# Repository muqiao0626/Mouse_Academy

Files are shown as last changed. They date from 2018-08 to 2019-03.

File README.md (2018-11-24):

# Mouse Academy

## Overview

Mouse Academy is an integrated platform for automated mice training. It is made of a social home cage, a radio frequency identification (RFID) access control tunnel and a training box. Mice are grouped together in the home cage where they can get free access to food and shelter. Water is provided only in the training box. Each mouse is implanted with a specific RFID chip whose information can be read from the RFID sensors. Based on the information from the RFID sensors, an Arduino circuit controls the opening of the gates, allowing only one animal at a time to access the training box. Once a mouse enters the training box, a protocol is initiated to train the mouse on a specific task using water rewards, and a video recording of the mouse’s behaviors is performed. The training box is controlled by Bpod, an open-source behavior control system (https://github.com/sanworks/Bpod).

## Content

## 1. Design files

The folder contains several CAD files for the hardware

## 2. Firmware and software

The folders MATLAB_PC and Python_RasPi contain the firmware and software designed for the specific system. In both folders, you can find:

### Firmware: Arduino program for RFID access control

#### Documentation

The code was written in Arduino language which has been tested on ARDUINO (IDE) 1.8.5. To run the code, you need to install the following packages:
```
Servo.h
```

#### Instruction in compiling and uploading the code

Compile the code in ARDUINO (IDE) 1.8.5 and upload it to Arduino Mega 2560

### Software and the instruction in running the software

Check the software folder and the corresponding txt files for instructions

## 3. Licence

These files are freely available under the terms of General Public License v3.0 (enclosed with this repository)

## 4. Acknowledgement

We thank Josh Sanders (Sanworks) for his advice on how to incorporate Bpod in Mouse Academy.

## 5. Contact

For more questions, please contact Mu Qiao at muqiao@caltech.edu and Sarah Sam at ssam@caltech.edu

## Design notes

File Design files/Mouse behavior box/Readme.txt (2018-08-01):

Note: This design for the mouse behavior box is undergoing validation.
It will almost certainly be revised many times in the coming year. A bill of materials is available on the Bpod wiki. JS, June 2015

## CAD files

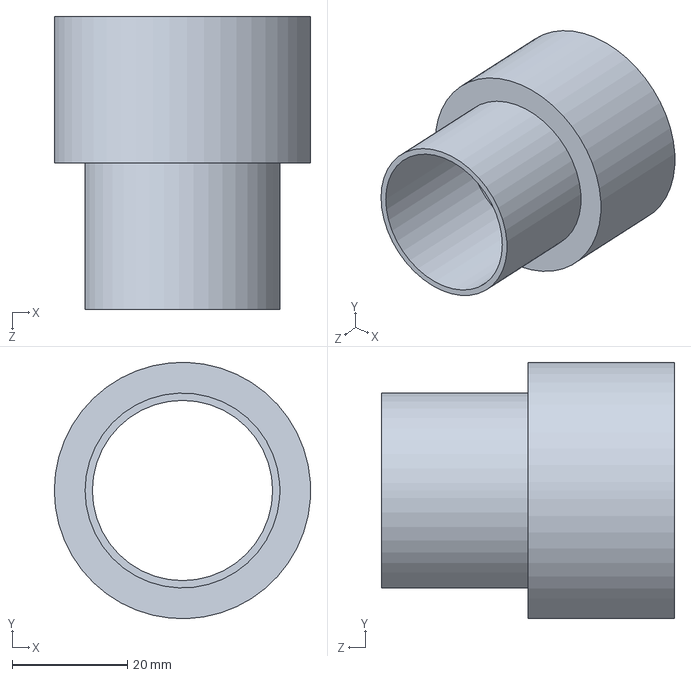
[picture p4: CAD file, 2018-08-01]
Design files/Adapter/adapter.SLDPRT
44.5 x 44.4 x 50.8 mm

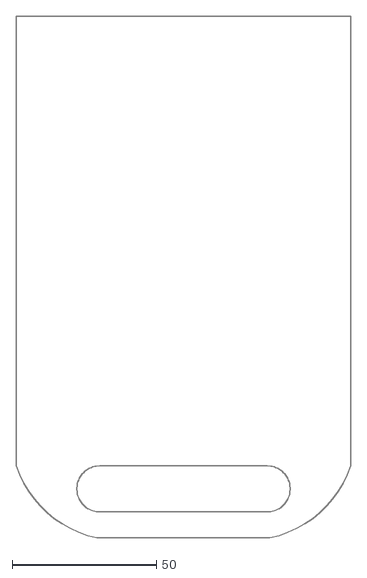
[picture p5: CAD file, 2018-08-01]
Design files/Mouse behavior box/2D DXF Laser Cut/Laser_Clear_3mm.dxf
116.0 x 181.0

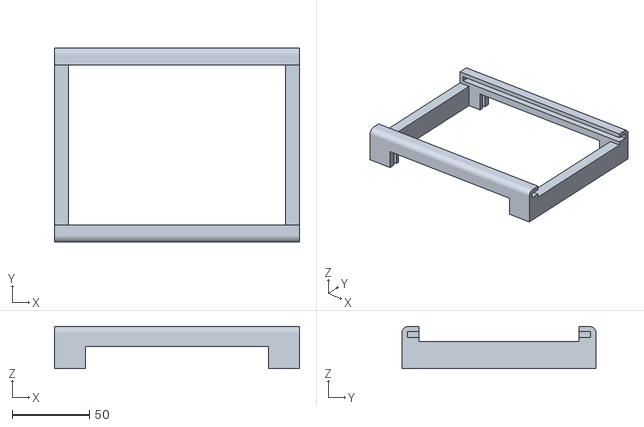
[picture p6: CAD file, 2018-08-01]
Design files/Mouse behavior box/3D STL Print/MouseBox_3dPrint_Top.stl
159.0 x 126.1 x 27.5

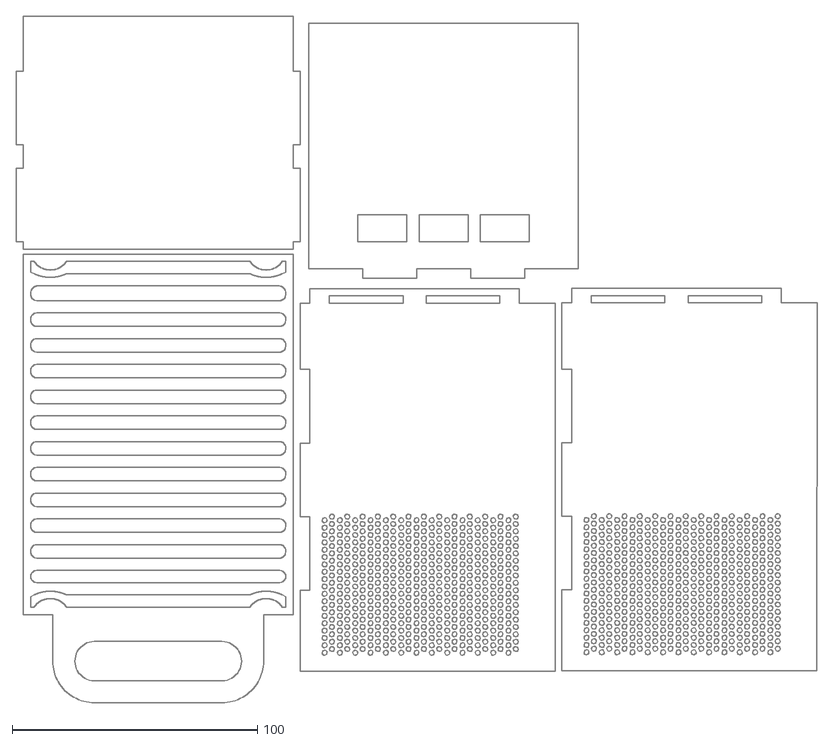
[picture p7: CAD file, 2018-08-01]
Design files/Mouse behavior box/2D DXF Laser Cut/Laser_White_3mm.dxf
326.7 x 280.0

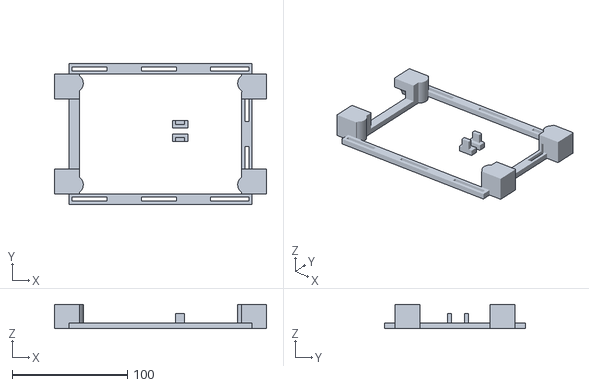
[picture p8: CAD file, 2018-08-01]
Design files/Mouse behavior box/3D STL Print/MouseBox_3dPrint_Base.stl
184.0 x 122.0 x 21.0

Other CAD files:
Design files/Adapter/adapter.STL

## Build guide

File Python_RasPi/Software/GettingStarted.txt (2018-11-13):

1) Activate python 3.5 environment with the command ~$ source activate py35
2) From the 'Software' directory, run ~$ python appendPath.py to add Mouse_Academy subfolders to the python search path.
3) Run ~$ python SoftwareTests.py to verify setup.
4) From the 'Modules' directory, run Enrollment.py to scan RFID tags and save tag IDs to file.
5) Valves dispense precise amounts of fluid by opening for a specific amount of time. From Software directory, run:
~$ python Calibrate/Calibrate.py <valve number> <pulse duration> <number of pulses>
For instance, to add a calibration point of 30 ms for valve 1 with 200 pulses, run command:
~$ python Calibrate/Calibrate.py 1 30 200
then enter the amount of water dispensed when prompted. Use at least 3 calibration points. Calibration curves are saved in the 'Calibrate' folder.

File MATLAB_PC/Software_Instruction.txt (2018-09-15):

# Software instruction
# Mu Qiao July/2018

The code was written in Matlab and has been tested under Matlab R2016a. To run the code, copy all the files under /Software/Matlab_PC/ into the MATLAB folder. Modify the ProtocolFiles.xlsx to include all the training procedures. The format of the excel file is: Procedure_name, Threshold_for_downgrade, Threshold_for_upgrade, Trials_in_a_session.

First, run Initialization.m to initialize the program. Then, run Master.m. The program runs in an infinite loop. To exit running, pause the program and then stop the Master.m program.

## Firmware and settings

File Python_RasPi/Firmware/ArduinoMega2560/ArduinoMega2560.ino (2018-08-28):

#include <Servo.h>
#include <stdio.h>

const int servoPin1 = 8;
const int servoPin2 = 9;

const int FSR_PIN1 = A0; // Pin connected to FSR/resistor divider
const int FSR_PIN2 = A1; // Pin connected to FSR/resistor divider
const float VCC = 5; // Measured voltage of Ardunio 5V line
const float R_DIV = 3300.0; // Measured resistance of 3.3k resistor

const int highWrite = 170;
const int lowWrite = 5;

const char readCompleteMsg[18] = "read tag complete";
const char openMsg[19] = "open door complete";
const char closeMsg[20] = "close door complete";
const char obstructMsg[24] = "obstruction encountered";
int idLen = 12;

char currentTag[13] = "000000000000";

Servo servo1;
Servo servo2;

int RFIDResetPin1 = 11;
int RFIDResetPin2 = 12;
int RFIDResetPin3 = 13;

char tag1[13];
char tag2[13];
char tag3[13];
float fsrForce;

const char blankTag[13] = "000000000000";
void setTag1(char newTag[13]) {
  for (int i = 0; i < 13; i++) {
    tag1[i] = newTag[i];
  }
}
void setTag2(char newTag[13]) {
  for (int i = 0; i < 13; i++) {
    tag2[i] = newTag[i];
  }
}
void setTag3(char newTag[13]) {
  for (int i = 0; i < 13; i++) {
    tag3[i] = newTag[i];
  }
}

void setup() {
  Serial.begin(9600);
  Serial.println("Mega is setting up...");
  Serial1.begin(9600);
  Serial2.begin(9600);
  Serial3.begin(9600);
  setTag1(blankTag);
  setTag2(blankTag);
  setTag3(blankTag);
  //reset RFID readers
  pinMode(RFIDResetPin1, INPUT);
  //digitalWrite(RFIDResetPin1, HIGH);
  pinMode(RFIDResetPin2, INPUT);
  //digitalWrite(RFIDResetPin2, HIGH);
  pinMode(RFIDResetPin3, INPUT);
  //digitalWrite(RFIDResetPin3, HIGH);

  pinMode(FSR_PIN1, INPUT);
  pinMode(FSR_PIN2, INPUT);

  servo1.attach(servoPin1, 400, 1900);
  delay(50);
  //openDoor(servo1, 1);
  //delay(50);
  servo2.attach(servoPin2, 500, 2000);
  delay(50);
  //closeDoor(servo2, 2);
  //delay(50);
  Serial.println("Mega is ready.");

}

void loop() {
  readTag(1);
  readTag(2);
  readTag(3);

  if (Serial.available() >= 2) {
    char commandRead = Serial.read();
    char idRead = Serial.read();

    //CHECKING FOR READ COMMAND
    if (commandRead == '8') {

      Serial.println(readCompleteMsg);
      if (idRead == '1') {
        Serial.println(tag1);
        setTag1(blankTag);
      }
      else if (idRead == '2') {
        Serial.println(tag2);
        setTag2(blankTag);
      }
      else if (idRead == '3') {
        Serial.println(tag3);
        setTag3(blankTag);
      }

    }

    //CHECKING FOR OPEN DOOR COMMAND
    else if (commandRead == '6') {
      if (idRead == '1') {
        openDoor(servo1);
      }
      if (idRead == '2') {
        openDoor(servo2);
      }
      Serial.println(openMsg);
    }

    //CHECKING FOR CLOSE DOOR COMMAND
    else if (commandRead == '7') {
      int closed = 0;
      if (idRead == '1') {
        closed = closeDoor(servo1, 1);
        if (closed == 1) {
          Serial.println(closeMsg);
        }
      }
      if (idRead == '2') {
        closed = closeDoor(servo2, 2);
        if (closed == 1) {
          Serial.println(closeMsg);
        }
      }
    }

  }
  delay(10);
}







// READ A TAG FROM A SINGLE RFID READER
void readTag(int tagNum) {
  currentTag[13] = "000000000000";
  HardwareSerial* serPointer;
   int address;

  if (tagNum == 1){
    serPointer = &Serial1;
  }
  else if (tagNum == 2){
    serPointer = &Serial2;
  }
  else if (tagNum == 3){
    serPointer = &Serial3;
  }
  boolean reading = false;
  int i = 0;
  int readByte;
  char peekByte;
  if (serPointer->available() >= 10) {
    peekByte = serPointer->peek(); //peep next available byte
    if (peekByte == 2) {
      readByte = serPointer->read();
      reading = true; //begining of tag

      while (reading == true) {
        readByte = serPointer->read();
        if (readByte == 3) {

          if (tagNum == 1) {
            setTag1(currentTag);
          }
          else if (tagNum == 2) {
            setTag2(currentTag);
          }
          else if (tagNum == 3) {
            setTag3(currentTag);
          }
          reading = false; //end of tag
        }

        else if (readByte != 10 && readByte != 13) {
          //store the tag
          if (i < sizeof(currentTag)) {
            currentTag[i] = readByte;
          }
          i++;
        }
        delay(2);
      }
    }
    else {
      reading = false;
    }
  }
}

int closeDoor(Servo servo, int servonum) {
  int pos = servo.read();
  int closed = 0;
  currentForce(servonum);
  float forceInit = fsrForce;
  float forceNow;
  //don't bother checking force at beginning and end
  for (int theta = pos; theta < highWrite - 6; theta += 6) {

    if (theta < lowWrite + 6 || theta > highWrite - 6) {
      servo.write(theta);
      delay(5);
      closed = 1;
    }



    else {
      servo.write(theta);
      delay(5);
      currentForce(servonum);
      forceNow = fsrForce - forceInit;
      if (forceNow > 10.0) {
        //reopen door
        servo.write(lowWrite);
        //print serial message that close door failed
        Serial.println(obstructMsg);
        //Serial.print(forceInit);
       // Serial.print(" forceNow: ");
        //Serial.println(forceNow);
        return 0;
      }
    }
  }
  //Serial.print("initForce ");
  //Serial.println(forceInit);
  return 1;
}

void openDoor(Servo servo) {
  int pos = servo.read();
  for (int theta = pos; theta > lowWrite + 3; theta -= 3) {
    servo.write(theta);
    delay(15);
  }
}


void currentForce(int doornum)
{
  int fsrADC;
  if (doornum == 1) {
    fsrADC = analogRead(FSR_PIN1);
  }
  else if (doornum == 2) {

    fsrADC = analogRead(FSR_PIN2);
  }
  // If the FSR has no pressure, the resistance will be
  // near infinite. So the voltage should be near 0.
  if (fsrADC != 0) // If the analog reading is non-zero
  {
    // Use ADC reading to calculate voltage:
    float fsrV = fsrADC * VCC / 1023.0;
    // Use voltage and static resistor value to
    // calculate FSR resistance:
    float fsrR = R_DIV * (VCC / fsrV - 1.0);
    float fsrG = 1.0 / fsrR;
    // Serial.println("Resistance: " + String(fsrR) + " ohms");
    // Guesstimate force based on slopes in figure 3 of
    // FSR datasheet:
    // Break parabolic curve down into two linear slopes:
    if (fsrR <= 600)
      fsrForce = (fsrG - 0.00075) / 0.00000032639;
    else
      fsrForce =  fsrG / 0.000000642857;

  }
  else{
    fsrForce = 0;
  }
}

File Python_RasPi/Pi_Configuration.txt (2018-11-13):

Raspberry pi configuration
Sarah Sam 08/20/18

1. Installing the OS
a) Purchase an Adafruit SD card that has NOOBS already installed OR
b) Download NOOBS from https://www.raspberrypi.org/downloads/noobs/ 
SD card should be 4-32 GB
extract downloaded file, copy all files from noobs directory to SD card root directory
2. Configure raspberry pi
a) change password
b) time preferences
c) language & keyboard
3. Python distribution: miniconda3
a) install per: https://stackoverflow.com/questions/39371772/how-to-install-anaconda-on-raspberry-pi-3-model-b 
1. wget http://repo.continuum.io/miniconda/Miniconda3-latest-Linux-armv7l.sh
2. md5sum Miniconda3-latest-Linux-armv7l.sh
3. bash Miniconda3-latest-Linux-armv7l.sh
4. Install numpy and pyserial
a) find python version
1. conda update conda
2. conda install anaconda-client
3. conda search "^python$"
b) create virtual python environment (ex. for python version 3.4.3)
1. conda create –n py34 python=3.4.3
2. source activate py34
c) Install NumPy
1. conda install numpy
d) Install pyserial
1. pip install pyserial
5. Install GNU Octave, Psychtoolbox, and oct2py
a) Octave
1. sudo apt-get install octave
b) PTB
1. http://neuro.debian.net/install_pkg.html?p=octave-psychtoolbox-3
2. sudo apt-get install octave-psychtoolbox-3
c) oct2py
1. pip install setuptools
2. pip install oct2py -I
6. Install Other Packages with pip
a) datetime
b) struct
7. Install Arduino IDE
a) installing:
1. sudo apt-get install arduino
2. sudo apt-get install dos2unix
3. wget https://raw.githubusercontent.com/wyolum/alamode/master/alamode-setup/stretch-setup
4. sudo dos2unix stretch-setup
b) correct version of java:
1. sudo apt-get remove openjdk-8-jre-headless
2. sudo apt-get install openjdk-8-jre

python 3.5:
conda config --add channels rpi
conda install python=3.5
conda create -n py35 python=3.5

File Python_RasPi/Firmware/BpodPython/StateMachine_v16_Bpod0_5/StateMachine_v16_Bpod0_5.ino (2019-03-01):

/*
  ----------------------------------------------------------------------------

  This file is part of the Sanworks Bpod_Gen2 repository
  Copyright (C) 2017 Sanworks LLC, Stony Brook, New York, USA

  ----------------------------------------------------------------------------

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
*/
// Bpod State Machine Firmware Ver. 16
//
// SYSTEM SETUP:
//
// IF COMPILING FOR Arduino DUE, Requires a small modification to Arduino, for useful PWM control of light intensity with small (1-10ms) pulses:
// change the PWM_FREQUENCY and TC_FREQUENCY constants to 50000 in the file /Arduino/hardware/arduino/sam/variants/arduino_due_x/variant.h
// or in Windows, \Users\Username\AppData\Local\Arduino15\packages\arduino\hardware\sam\1.6.7\variants\arduino_due_x\variant.h
//
// IF COMPILING FOR TEENSY 3.6, Requires modifications to Teensy core files:
// In the folder /arduino-1.8.X/hardware/teensy/avr/cores/teensy3, modify the following line in each of the 5 files listed below:
// #define SERIAL1_RX_BUFFER_SIZE 64  --> #define SERIAL1_RX_BUFFER_SIZE 256
// IN FILES: serial1.c, serial2.c, serial3.c, serial4.c, serial5.c

//////////////////////////////////////////
// Set hardware series (0.5, 0.7+, etc)  /
//////////////////////////////////////////
// 1 = Bpod 0.5 (Arduino Due); 2 = Bpod 0.7-0.9 (Arduino Due); 3 = Pocket State Machine (Teensy 3.6)

#define MachineType 1 

//////////////////////////////////////////
//          Set Firmware Version         /
//////////////////////////////////////////
// Current firmware version (single firmware file, compiles for MachineTypes set above)

#define FirmwareVersion 16

//////////////////////////////////////////
//          Board configuration          /
//////////////////////////////////////////

// Board configuration (universal)
#define useStatusLED 1 // Set to 0 to disable the board's red/green/blue status LED

// Board configuration (machine-specific)
#if MachineType < 3
  #include "DueTimer.h"
#endif
#include <SPI.h>
#include "ArCOM.h" // ArCOM is a serial interface wrapper developed by Sanworks, 
                   // to streamline transmission of datatypes and arrays over USB and UART
#define SERIAL_TX_BUFFER_SIZE 256
#define SERIAL_RX_BUFFER_SIZE 256
#if MachineType == 1
  ArCOM USBCOM(SerialUSB); // Creates an ArCOM object called USBCOM, wrapping SerialUSB
  ArCOM Serial1COM(Serial1); // Creates an ArCOM object called Serial1COM, wrapping Serial1
  ArCOM Serial2COM(Serial2); 
#elif MachineType == 2
  ArCOM USBCOM(SerialUSB); 
  ArCOM Serial1COM(Serial1); 
  ArCOM Serial2COM(Serial2); 
  ArCOM Serial3COM(Serial3);
#elif MachineType == 3
  ArCOM USBCOM(Serial); // Creates an ArCOM object called USBCOM, wrapping Serial (for Teensy 3.6)
  ArCOM Serial1COM(Serial1); // Creates an ArCOM object called Serial1COM, wrapping Serial1
  ArCOM Serial2COM(Serial3); 
  ArCOM Serial3COM(Serial2); 
  ArCOM Serial4COM(Serial4); 
  ArCOM Serial5COM(Serial5); 
#endif

////////////////////////////////////////
// State machine hardware description  /
////////////////////////////////////////
// Two pairs of arrays describe the hardware as it appears to the state machine: inputHW / inputCh, and outputHW / outputCh.
// In these arrays, the first row codes for hardware type. U = UART, X = USB, S = SPI,  D = digital, B = BNC (digital/inverted), W = Wire (digital/inverted) 
// P = port (digital channel if input, PWM channel if output). Channels must be listed IN THIS ORDER (this constraint allows efficient code at runtime). 
// The digital,BNC or wire channel currently replaced by 'Y' is the sync channel (none by default).
// The second row lists the physical input and output channels on Arduino for B,W,P, and the SPI CS pin is listed for S. Use 0 for UART and USB.

#if MachineType == 1 // Bpod state machine v0.5
    byte InputHW[] = {'U','U','X','B','B','W','W','W','W','P','P','P','P','P','P','P','P'};
    byte InputCh[] = {0,0,0,11,10,35,33,31,29,28,30,32,34,36,38,40,42};                                         
    byte OutputHW[] = {'U','U','X','S','B','B','W','W','W','W','P','P','P','P','P','P','P','P'};
    byte OutputCh[] = {0,0,0,22,25,24,43,41,39,37,9,8,7,6,5,4,3,2};  
#elif MachineType == 2 // Bpod State Machine r0.7+
    byte InputHW[] = {'U','U','U','X','B','B','W','W','P','P','P','P','P','P','P','P'};
    byte InputCh[] = {0,0,0,0,10,11,31,29,28,30,32,34,36,38,40,42};                                         
    byte OutputHW[] = {'U','U','U','X','S','B','B','W','W','W','P','P','P','P','P','P','P','P'};
    byte OutputCh[] = {0,0,0,0,22,25,24,43,41,39,9,8,7,6,5,4,3,2};  
#elif MachineType == 3 // Teensy 3.6-based "Pocket" state machine
    byte InputHW[] = {'U','U','U','U','U','X','B','B'};
    byte InputCh[] = {0,0,0,0,0,0,16,17};                                         
    byte OutputHW[] = {'U','U','U','U','U','X','B','B'};
    byte OutputCh[] = {0,0,0,0,0,0,36,37};  
#endif

// State machine meta information
const byte nInputs = sizeof(InputHW);
const byte nOutputs = sizeof(OutputHW);
#if MachineType == 1 // State machine (Bpod 0.5)
  const byte nSerialChannels = 3;
  const byte maxSerialEvents = 30;
  const int MaxStates = 128;
  const int SerialBaudRate = 115200;
#elif MachineType == 2 // Bpod State Machine r0.7+
  const byte nSerialChannels = 4; // Must match total of 'U' and 'X' in InputHW (above)
  const byte maxSerialEvents = 60; // Must be a multiple of nSerialChannels
  const int MaxStates = 256;
  const int SerialBaudRate = 1312500;
#elif MachineType == 3  // Teensy 3.6 based state machines (Pocket state machine)
  const byte nSerialChannels = 6; 
  const byte maxSerialEvents = 120;
  const int MaxStates = 256;
  const int SerialBaudRate = 1312500;
#endif
const byte nGlobalTimers = 5;
const byte nGlobalCounters = 5;
const byte nConditions = 5;
uint16_t timerPeriod = 100; // Hardware timer period, in microseconds (state machine refresh period)
                         
// Other hardware pin mapping
#if MachineType == 1
  byte GreenLEDPin = 14;
  byte RedLEDPin = 13;
  byte BlueLEDPin = 12;
#elif MachineType == 2
  byte GreenLEDPin = 33;
  byte RedLEDPin = 13;
  byte BlueLEDPin = 12;
#elif MachineType == 3
  byte GreenLEDPin = 30;
  byte RedLEDPin = 29;
  byte BlueLEDPin = 35;
#endif

byte fRAMcs = 1;
byte fRAMhold = A3;
byte SyncRegisterLatch = 23;

// Settings for version-specific hardware (initialized in setup)
boolean usesFRAM = false;
boolean usesSPISync = false;
boolean usesUARTInputs = false;
boolean isolatorHigh = 0;
boolean isolatorLow = 0;

// Bookmarks (positions of channel types in hardware description vectors, to be calculated in setup)
byte USBInputPos = 0;
byte BNCInputPos = 0;
byte WireInputPos = 0;
byte PortInputPos = 0;
byte USBOutputPos = 0;
byte SPIOutputPos = 0;
byte BNCOutputPos = 0;
byte WireOutputPos = 0;
byte PortOutputPos = 0;

// Parameters

const unsigned long ModuleIDTimeout = 100; // timeout for modules to respond to byte 255 (units = 100us cycles). Byte 255 polls for module hardware information
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

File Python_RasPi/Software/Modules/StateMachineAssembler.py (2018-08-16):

'''
----------------------------------------------------------------------------

This file is part of the Sanworks Bpod repository
Copyright (C) 2017 Sanworks LLC, Stony Brook, New York, USA

----------------------------------------------------------------------------

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
You should have received a copy of the GNU General Public License
along with this program.  If not, see <http://www.gnu.org/licenses/>.
'''
import os, sys
sys.path.append("Bpod_Gen2-new/Python 3/Modules") # Add Bpod system files to Python path
import struct
import math
class stateMachine(object):
    def __init__(self, bpodObject):
        self.nStates = 0
        self.eventNames = bpodObject.stateMachineInfo.eventNames;
        self.outputChannelNames = bpodObject.stateMachineInfo.outputChannelNames
        self.metaOutputNames = ('Valve', 'LED', 'SoftCode')
        self.stateNames = []
        self.stateTimers = [0]*bpodObject.stateMachineInfo.maxStates;
        self.stateTimerMatrix = [0]*bpodObject.stateMachineInfo.maxStates;
        self.inputMatrix = [[] for i in range(bpodObject.stateMachineInfo.maxStates)]
        self.outputMatrix = [[] for i in range(bpodObject.stateMachineInfo.maxStates)]

        self.globalTimers = Struct()
        self.globalTimers.startMatrix = [[] for i in range(bpodObject.stateMachineInfo.maxStates)]
        self.globalTimers.endMatrix = [[] for i in range(bpodObject.stateMachineInfo.maxStates)]
        self.globalTimers.timers = [0]*bpodObject.HW.n.GlobalTimers
        self.globalTimers.onsetDelays = [0]*bpodObject.HW.n.GlobalTimers
        self.globalTimers.channels = [0]*bpodObject.HW.n.GlobalTimers
        self.globalTimers.onMessages = [0]*bpodObject.HW.n.GlobalTimers
        self.globalTimers.offMessages = [0]*bpodObject.HW.n.GlobalTimers
        self.globalTimers.loopMode = [0]*bpodObject.HW.n.GlobalTimers
        self.globalTimers.loopIntervals = [0]*bpodObject.HW.n.GlobalTimers
        self.globalTimers.sendEvents = [0]*bpodObject.HW.n.GlobalTimers
        self.globalCounters = Struct()
        self.globalCounters.attachedEvents = [254]*bpodObject.HW.n.GlobalCounters
        self.globalCounters.thresholds = [0]*bpodObject.HW.n.GlobalCounters
        self.globalCounters.matrix = [[] for i in range(bpodObject.stateMachineInfo.maxStates)]
        self.conditions = Struct()
        self.conditions.channels = [0]*bpodObject.HW.n.Conditions
        self.conditions.values = [0]*bpodObject.HW.n.Conditions
        self.conditions.matrix = [[] for i in range(bpodObject.stateMachineInfo.maxStates)]
        self.manifest = [] # List of states that have been added to the state machine
        self.undeclared = [] # List of states that have been referenced but not yet added
        self.stateMachineInfo = bpodObject.stateMachineInfo
    def addState(self, *args):
        nargs = len(args)
        for i in range(0,nargs,2):
            thisArg = args[i].lower()
            thisArgValue = args[i+1]
            if thisArg == 'name':
                if thisArgValue not in self.manifest:
                    self.stateNames.append(thisArgValue)
                    self.manifest.append(thisArgValue)
                    thisStateNumber = len(self.manifest)-1
                else:
                    thisStateNumber = self.manifest.index(thisArgValue)
                    self.stateNames[thisStateNumber] = thisArgValue
                self.stateTimerMatrix[thisStateNumber] = thisStateNumber
            elif thisArg == 'timer':
                self.stateTimers[thisStateNumber] = thisArgValue
            elif thisArg == 'statechangeconditions':
                conditionList = thisArgValue;
                nconditions = len(conditionList)
                for i in range(0,nconditions,2):
                    try:
                        thisEventCode = self.eventNames.index(conditionList[i])
                    except:
                        raise SMAError('Error creating state: ' + self.stateNames[-1] + '. ' + conditionList[i] + ' is an invalid event name.')
                    thisEventStateTransition = conditionList[i+1]
                    if thisEventStateTransition in self.manifest:
                        destinationStateNumber = self.manifest.index(thisEventStateTransition)
                    else:
                        if thisEventStateTransition == 'exit':
                            destinationStateNumber = float('NaN')
                        else: # Send to an undeclared state (replaced later with actual state in myBpod.sendStateMachine)
                            self.undeclared.append(thisEventStateTransition)
                            destinationStateNumber = (len(self.undeclared)-1)+10000
                    if thisEventCode == self.stateMachineInfo.Pos.Tup:
                        self.stateTimerMatrix[thisStateNumber] = destinationStateNumber
                    elif thisEventCode >= self.stateMachineInfo.Pos.condition:
                        self.conditions.matrix[thisStateNumber].append((thisEventCode,destinationStateNumber))
                    elif thisEventCode >= self.stateMachineInfo.Pos.globalCounter:
                        self.globalCounters.matrix[thisStateNumber].append((thisEventCode,destinationStateNumber))
                    elif thisEventCode >= self.stateMachineInfo.Pos.globalTimerEnd:
                        self.globalTimers.endMatrix[thisStateNumber].append((thisEventCode,destinationStateNumber))
                    elif thisEventCode >= self.stateMachineInfo.Pos.globalTimerStart:
                        self.globalTimers.startMatrix[thisStateNumber].append((thisEventCode,destinationStateNumber))
                    else:
                        self.inputMatrix[thisStateNumber].append((thisEventCode,destinationStateNumber))
            elif thisArg == 'outputactions':
                outputActionList = thisArgValue;
                nactions = len(outputActionList)
                for i in range(0,nactions,2):
                    thisAction = outputActionList[i]
                    if thisAction in self.metaOutputNames:
                        metaAction = self.metaOutputNames.index(thisAction)
                        value = outputActionList[i+1]
                        if metaAction == 0: # Valve
                            thisOutputCode = self.outputChannelNames.index('ValveState')
                            thisOutputValue = int(math.pow(2,value-1))
                        elif metaAction == 1: # LED
                            thisOutputCode = self.outputChannelNames.index('PWM' + str(value))
                            thisOutputValue = 255;
                        elif metaAction == 2: # SoftCode
                            thisOutputCode = self.outputChannelNames.index('SoftCode')
                            thisOutputValue = value;
                        else:
                            raise SMAError('Error: a meta-action was unhandled.')
                    else:
                        try:
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

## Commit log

2018-08-01 second commit
    [Laser_Clear_3mm.dxf, Laser_White_3mm.dxf, MouseBox_3dPrint_Base.stl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]
2018-08-16 Create ArCOM.py
    Sanworks protocol for facilitating communication between Python and Arduino.
2018-08-16 Create Calibrate.py
    Bpod protocol for valve calibration.
2018-08-21 Adding passed tests for running ProtocolTemplate and Calibrate
2018-08-27 Arduino memory leak patch
    [ArduinoMega2560.ino]
2018-09-14 adding softcode handler for protocol template
    [Pi_Configuration.txt]
2018-10-23 switch valves quickly from high to low during setup to avoid valve opening when bpod is reset
    [StateMachine_v16_Bpod0_5.ino]
2018-11-13 remove note about not neurodebian not being required
    [Pi_Configuration.txt]
2018-11-13 adding valve calibration instructions
2019-03-01 changed pound signs to proper arduino comment indicator

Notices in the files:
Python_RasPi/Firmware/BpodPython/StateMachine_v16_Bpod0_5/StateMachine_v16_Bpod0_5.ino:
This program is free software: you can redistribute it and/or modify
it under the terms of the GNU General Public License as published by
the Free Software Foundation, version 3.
